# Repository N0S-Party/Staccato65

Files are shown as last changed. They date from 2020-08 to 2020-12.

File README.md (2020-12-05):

# Staccato65

[][cc-by-nc-sa]

A 65% board with OLED, rotary encoder support, and a 3D printed case.

Keyboard_black

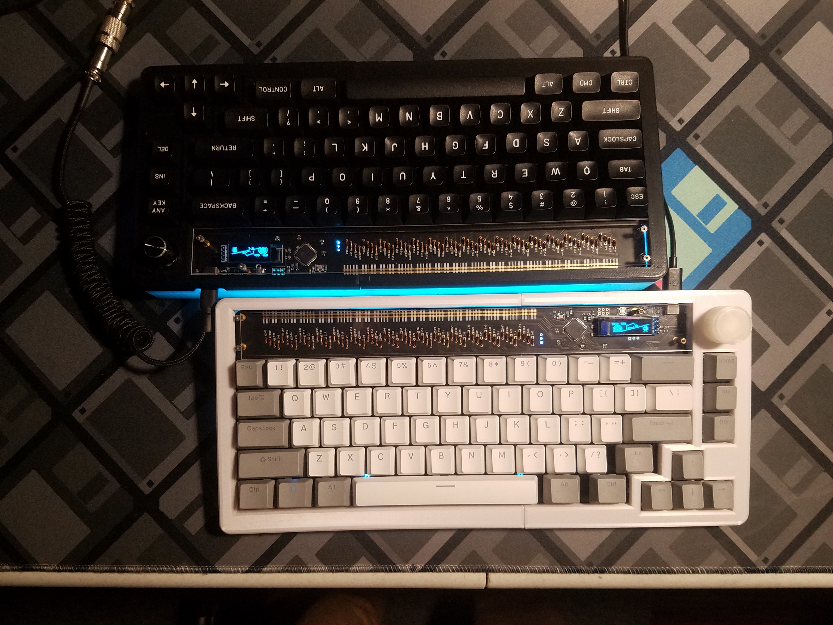
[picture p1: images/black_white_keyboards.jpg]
Keyboard_black_white


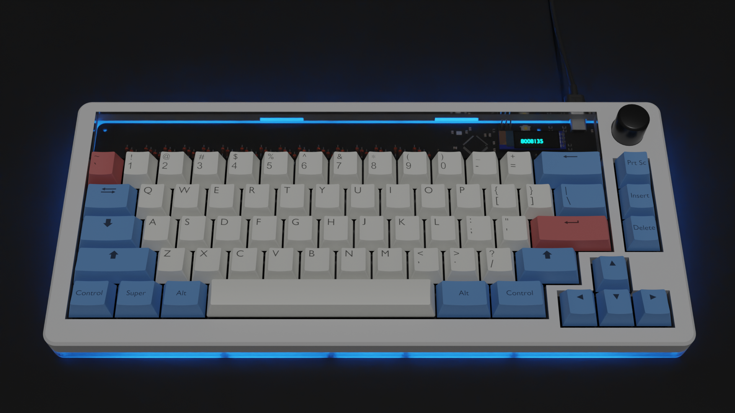
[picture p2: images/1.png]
Keyboard


**Specs:** 
* 3D printed case (top mounted)
* rotary encoder support
* OLED screen
* ATMega32u4 as microcontroller
* USB C connector (with USB 2.0)
* choice of a stepped caps lock
* hot-swappable (if I don't end up cutting costs!)

**Design goals:**
* separated arrow keys
* 1.5u alt & ctrl keys with 1.75u shift
* aesthetically pleasing through-hole diode layout on the front layer

Basically the layout will be similar to the Satisfaction75 and ID80, but without the function row. 
I also really like the look of the Discipline keyboards, so the layout of the diodes will somewhat try to reflect that. 

One of my current concerns is that the firmware size might end up too big, since I'll have to use QMK's I2C and roatry encoder libraries in addition to multiple keyboard layouts -- 
but I guess we'll see once we get there.

## Update 8/1
I started building the key matrix in the schematic. I originally wanted the schematic matrix to have a 1-to-1 mapping to the keyboard layout. 
It's actually done that way for the schematic of the Discipline, making it easy to route the traces for the PCB, and organize the layout even pre-PCB design.
Unfortunately, it ended up being 15 columns by 6 rows for me. 
This was far too many pins to support for the ATmega32u4 since I need to save some pins to support the rotary encoder and OLED. 
I'm also planning to save the SCK, MOSI and MISO pins for ISP usage, in case I ever want to set fuse bits 
(though I'm willing to give these pins up if desperate measures need to be in play).

## Update 8/4
Modified the matrix to now use 10 columns and 7 rows. This allows for a maximum of 69 switches and 1 rotary encoder switch. With the rotary encoder and OLED screen added, this oleaves the microcontroller with only one GPIO pin available (which means I *could* turn this into a 75% keyboard). I did come across [mr.keeb's PCB generator](https://builder.mrkeebs.com), but for some reason there is a bug that messes up the layout if you use a non-standard matrix; Can't say I'm not happy, since this means that my previous work wasn't all for nothing. I'm planning on using Kailh hot-swap sockets, but I might undo this if I find that it's too costly. 

## Update 8/6
Got to making the key layout on the PCB. I'm thankful I have a spare top plate and a caliper to help me confirm my switch placement. A modification I made from my initial plan is that I'm now using the "columns" in the schematics as rows. I need about 14 keys per row, and have 7 keys per column in the schematic makes that transform easy. I'll now have two disjoint traces per row on the PCB. Also, I can't get that damn encoder footprint to be centered... I'll leave that for next time.

## Update 8/12
I haven't updated here in a while, but that doesn't mean I haven't been working hard! I've finally managed to finish routing the PCB to a degree that I'm satisfied with. I might have to work a bit more on making the top right routing better, but I'd say the key routing was not too shabby. Fun fact, using Kicad 5.0.2 makes routing a pain. Traces never consistently "stuck" to each other the way I wanted it to. Thankfully, Kicad 5.1.6 was way more route-friendly. Unfortunately I couldn't really group the traces into fours that were aligned with the diode groups since some of the rows contained five switches instead of four. Nevertheless, clean routing was still possible and it still looks good as long as you don't look at it too hard. See below for pictures (you can see what I was talking about with the schematic matrix not being entirely 1-to-1 in dimension to the keyboard).

PCB and Schematics pictured are outdated. Please see the repo files for the updated versions
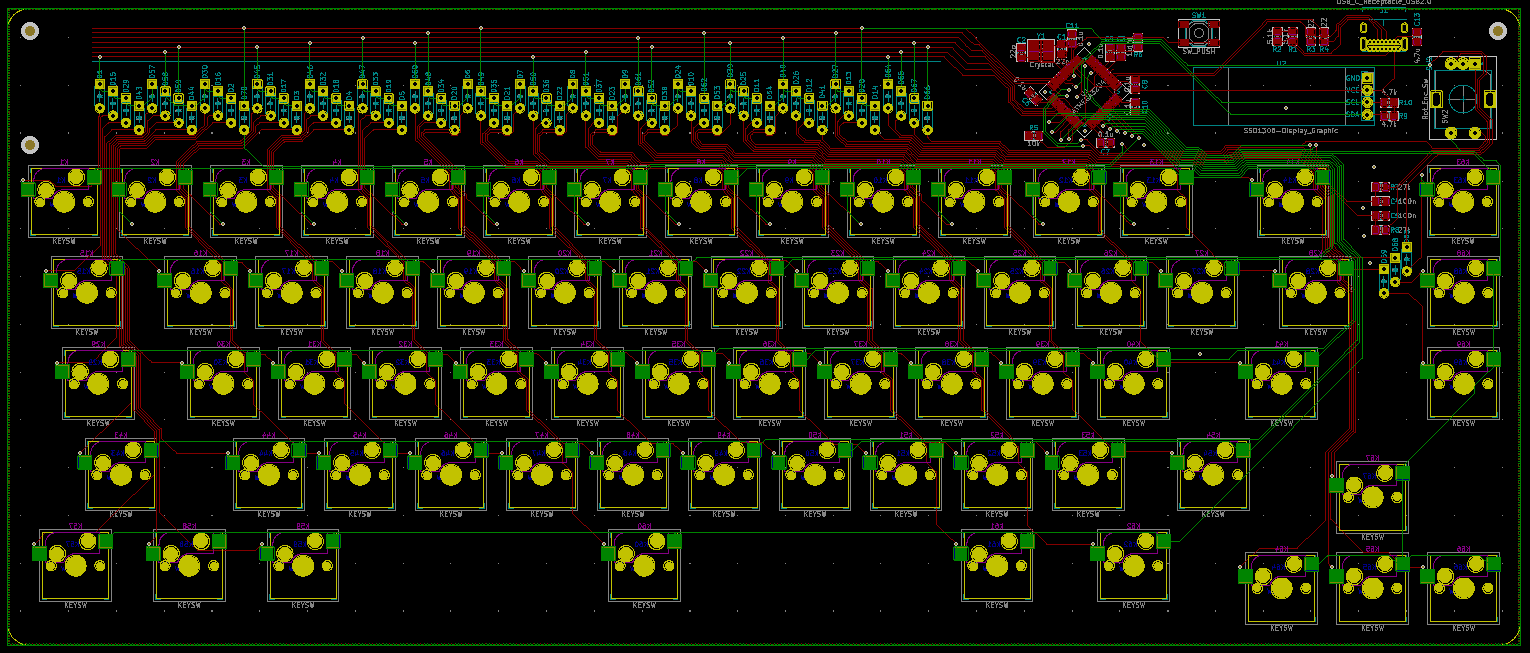
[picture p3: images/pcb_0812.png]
PCB


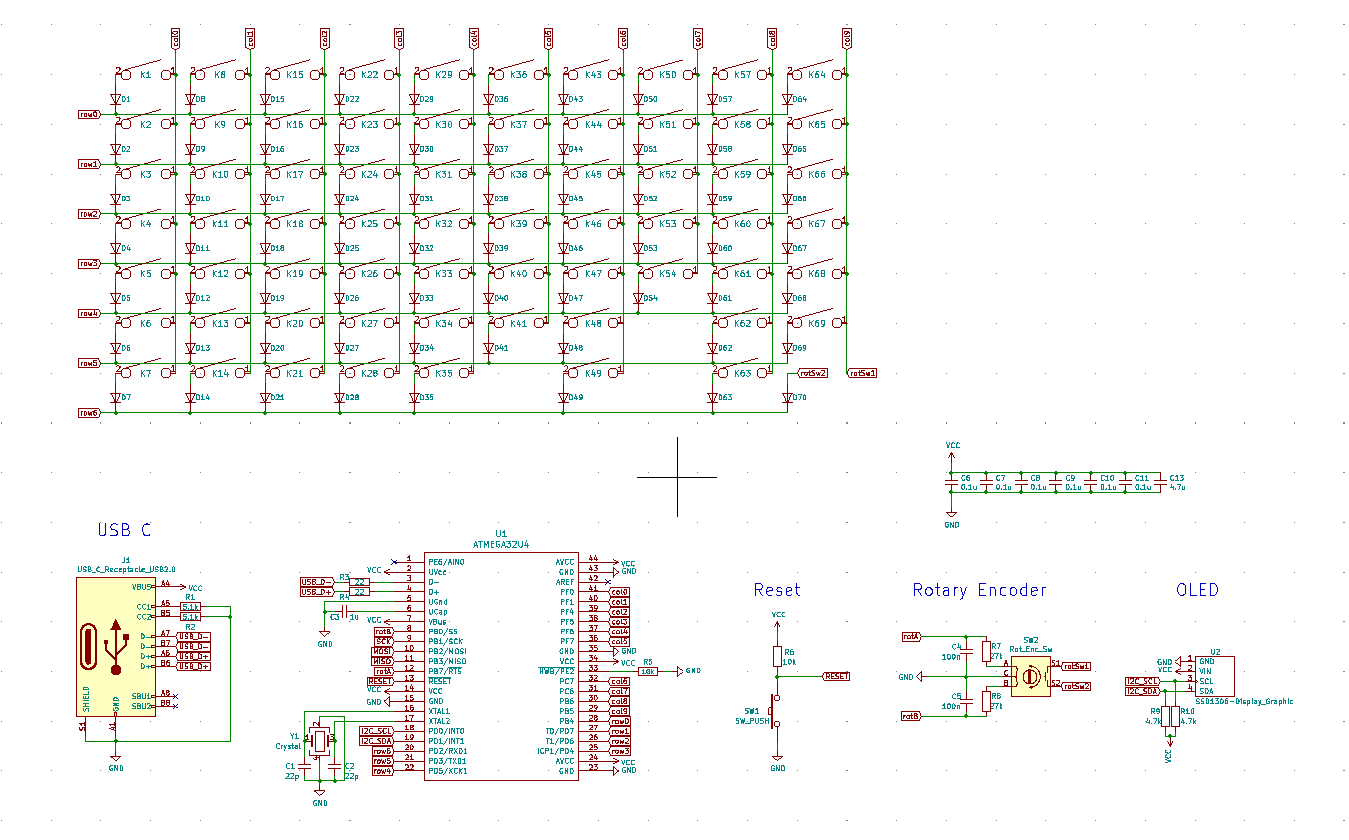
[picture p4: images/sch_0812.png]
Schematic


## Update 12/5
Okay, I don't know if anyone was following this project, but while it did seem like I had a long hiatus, I was actually working quite a bit behind the scenes. 
With the help of Sagar, and another friend of ours, we managed to get the first few prototypes out. Many revisions had to be done with the case due to 3D printing tolerances and the limitations of a 3D printer. Another issue that was caught was that the PCB plate cutout for the spacebar stabilizer was actually facing the wrong way. Unfortunately I only found this out after I got the first batch delivered, so I just had to file down the troublesome cutout by a few milimeters. Ordering from JLC PCB, the cumulative costs of PCB + plate + parts is about 70 dollars, assuming you order a batch of 10. Surprisingly, we managed to get a small groupbuy going and will be making 10 keyboards for us and a few other friends. In terms of regrets, I maybe should have opted to pay for assembly costs from the fab as well, since soldering a keyboard takes about 4 hours total. But hey, I'm really good at drag soldering now at least. As for actual release, I'm not too confident in my PCB design skills yet to release a product to members of the community. If I ever had to refine this design for a round 2, I'd probably add ESD protection, fix the plate and also make some of the footprint placements nicer. Overall, I plan to make a macropad as my next project. The reasoning is so I could try out more experimental features that I've had in mind while keeping the risk low. We also hope to make a case out of metal, which may be a challenge in itself. 

This work is licensed under a
[Creative Commons Attribution-NonCommercial-ShareAlike 4.0 International License][cc-by-nc-sa].

[][cc-by-nc-sa]

[cc-by-nc-sa]: http://creativecommons.org/licenses/by-nc-sa/4.0/
[cc-by-nc-sa-image]: https://licensebuttons.net/l/by-nc-sa/4.0/88x31.png
[cc-by-nc-sa-shield]: https://img.shields.io/badge/License-CC%20BY--NC--SA%204.0-lightgrey.svg

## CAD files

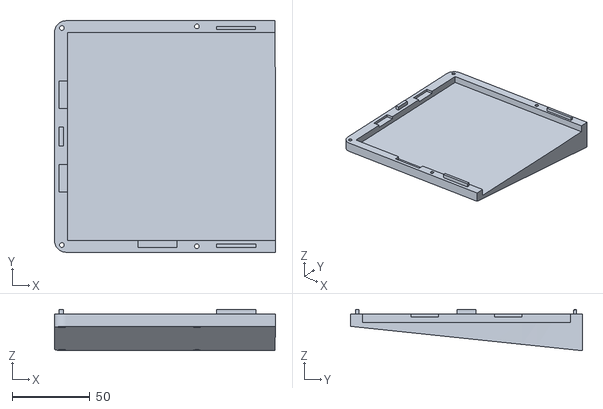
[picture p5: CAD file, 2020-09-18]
3d/case_bottom_left.stl
142.2 x 149.0 x 26.7

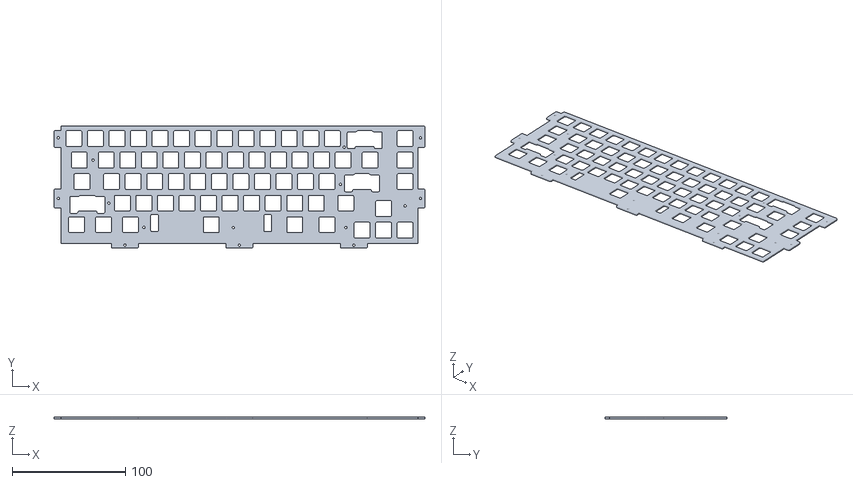
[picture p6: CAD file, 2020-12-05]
keybored_plate/staccato65_plate.obj
328.1 x 108.0 x 1.60

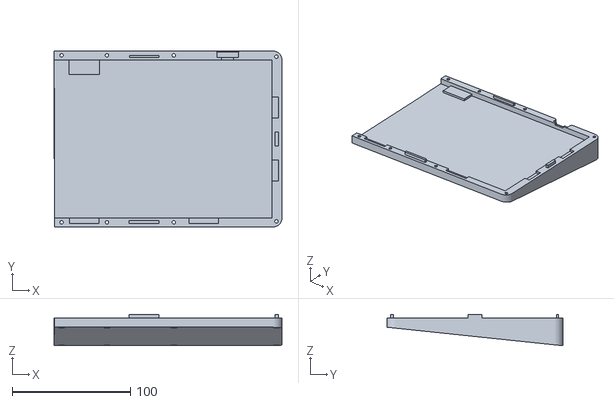
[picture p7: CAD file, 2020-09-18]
3d/case_bottom_right.stl
193.2 x 149.0 x 26.7

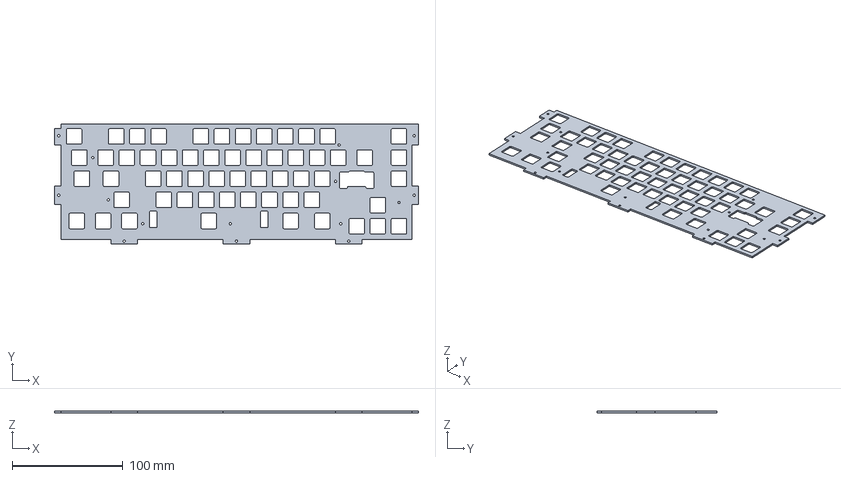
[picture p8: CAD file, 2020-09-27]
keybored_plate/keybored_plate.step
328.1 x 108.0 x 1.60 mm

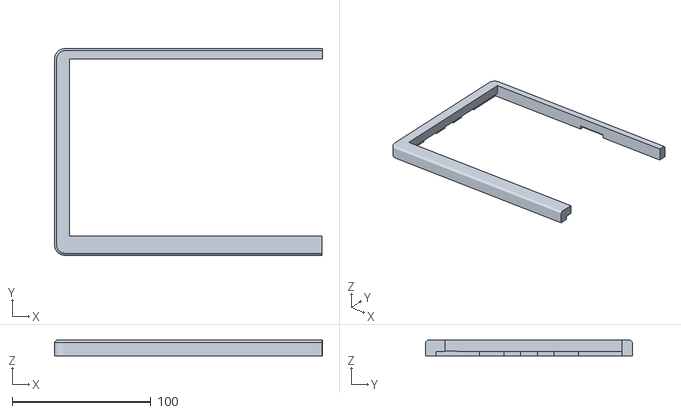
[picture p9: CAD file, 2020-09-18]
3d/case_top_left.stl
193.2 x 149.0 x 11.3

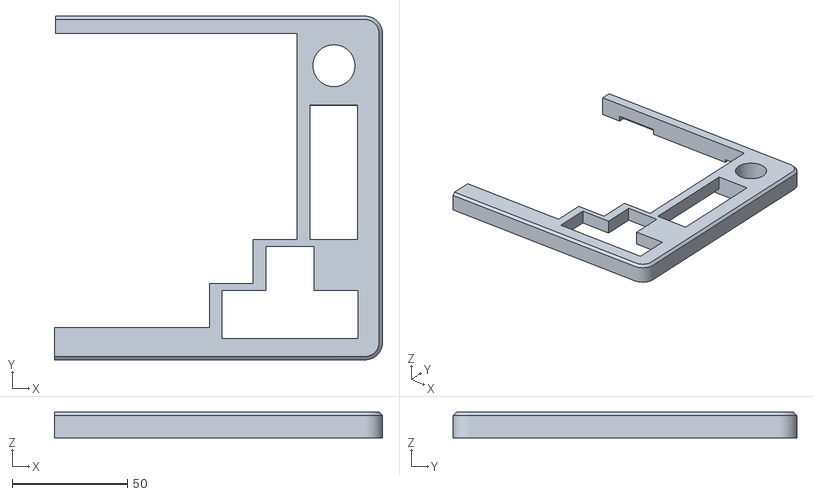
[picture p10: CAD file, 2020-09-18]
3d/case_top_right.stl
142.2 x 149.0 x 11.3

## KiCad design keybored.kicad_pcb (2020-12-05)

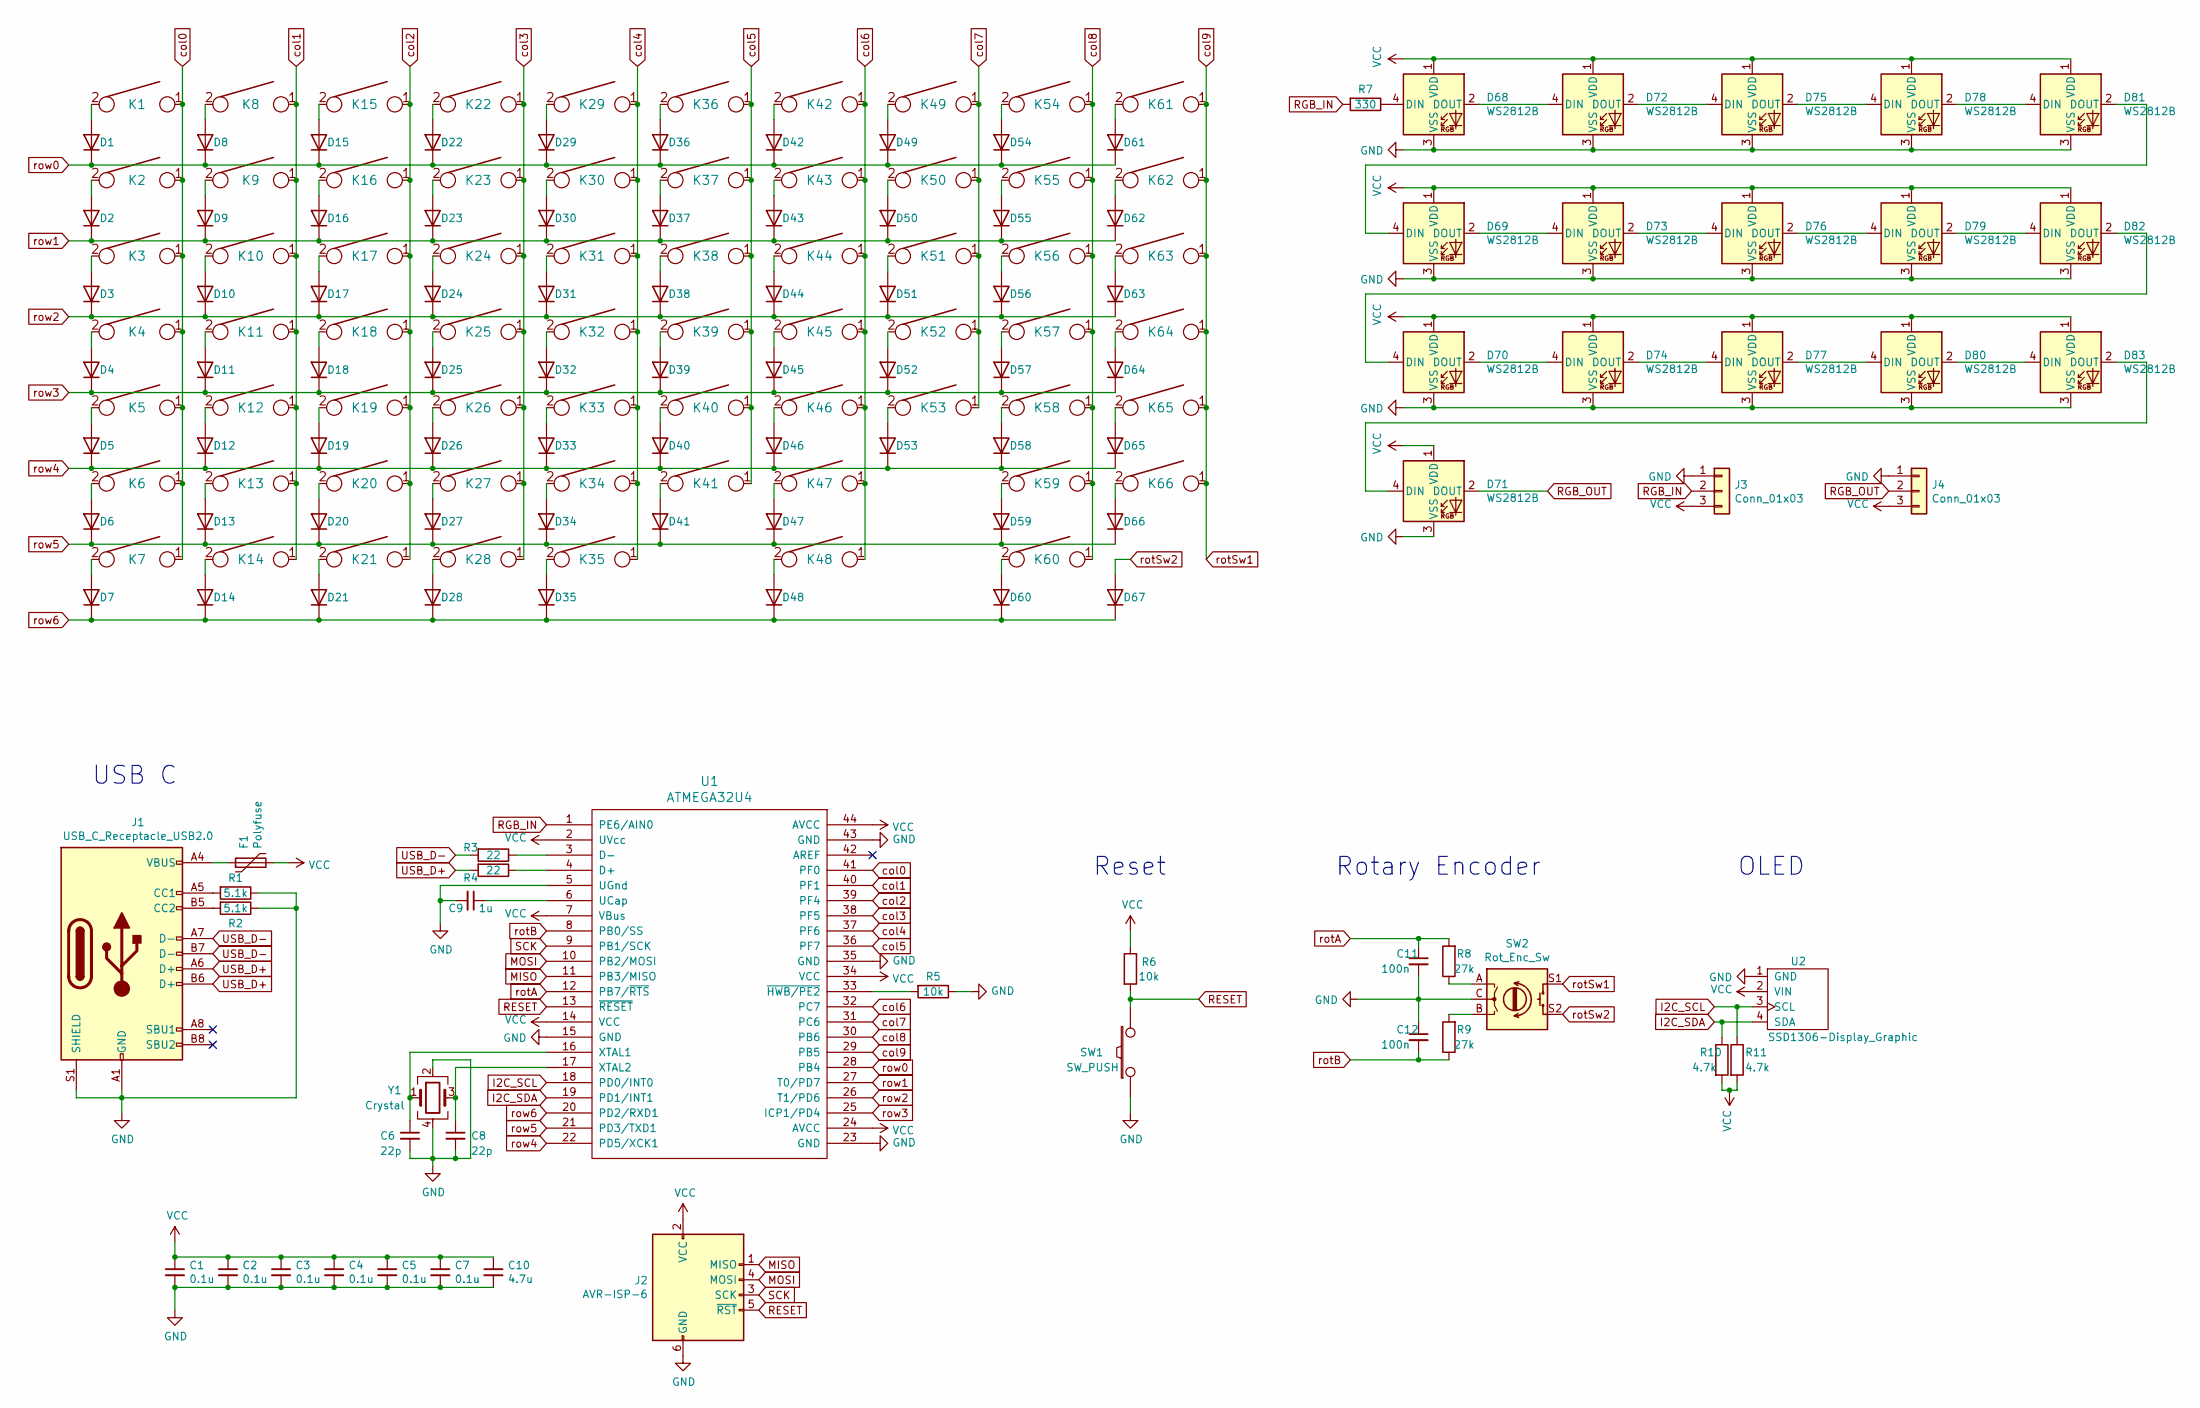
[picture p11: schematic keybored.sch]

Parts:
C1, C2, C3, C4, C5, C7: 0.1u; C_0805_2012Metric_Pad1.15x1.40mm_HandSolder
C6, C8: 22p; C_0805_2012Metric_Pad1.15x1.40mm_HandSolder
C9: 1u; C_0805_2012Metric_Pad1.15x1.40mm_HandSolder
C10: 4.7u; C_0805_2012Metric_Pad1.15x1.40mm_HandSolder
C11, C12: 100n; C_0805_2012Metric_Pad1.15x1.40mm_HandSolder
D1, D2, D3, D4, D5, D6, D7, D8, D9, D10, D11, D12, D13, D14, D15, D16, D17, D18, D19, D20, D21, D22, D23, D24, D25, D26, D27, D28, D29, D30, D31, D32, D33, D34, D35, D36, D37, D38, D39, D40, D41, D42, D43, D44, D45, D46, D47, D48, D49, D50, D51, D52, D53, D54, D55, D56, D57, D58, D59, D60, D61, D62, D63, D64, D65, D66, D67: D; DO-35_SOD27_5.08mm
D68, D69, D70, D71, D72, D73, D74, D75, D76, D77, D78, D79, D80, D81, D82, D83: WS2812B; LED_WS2812B_PLCC4_5.0x5.0mm_P3.2mm
F1: Polyfuse
J1: USB_C_Receptacle_USB2.0; USB_C_GCT_USB4085
J2: AVR-ISP-6; PinHeader_2x03_P2.54mm_Vertical
J3, J4: Conn_01x03; PinHeader_1x03_P2.54mm_Vertical
K1, K2, K3, K4, K5, K6, K7, K8, K9, K10, K11, K12, K13, K14, K15, K16, K17, K18, K19, K20, K21, K22, K23, K24, K25, K26, K27, K28, K29, K30, K31, K32, K33, K34, K35, K36, K37, K38, K39, K40, K41, K42, K43, K44, K45, K46, K47, K48, K49, K50, K51, K52, K53, K54, K55, K56, K57, K58, K59, K60, K61, K62, K63, K64, K65, K66: KEYSW; Kailh_socket_MX_optional
R1, R2: 5.1k; R_0805_2012Metric_Pad1.15x1.40mm_HandSolder
R3, R4: 22; R_0805_2012Metric_Pad1.15x1.40mm_HandSolder
R5, R6: 10k; R_0805_2012Metric_Pad1.15x1.40mm_HandSolder
R7: 330; R_0805_2012Metric_Pad1.15x1.40mm_HandSolder
R8, R9: 27k; R_0805_2012Metric_Pad1.15x1.40mm_HandSolder
R10, R11: 4.7k; R_0805_2012Metric_Pad1.15x1.40mm_HandSolder
SW1: SW_PUSH; SW_SPST_TL3342
SW2: Rot_Enc_Sw; RotaryEncoder_Alps_EC11E-Switch_Vertical_H20mm
U1: ATMEGA32U4; TQFP-44_10x10mm_P0.8mm
U2: SSD1306-Display_Graphic; SSD1306_OLED_128x32_0.91_inch
Y1: Crystal; Crystal_SMD_SeikoEpson_FA238-4Pin_3.2x2.5mm_HandSoldering

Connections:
GND: C1.2, C2.2, C3.2, C4.2, C5.2, C6.2, C7.2, C8.2, C9.2, C10.2, C11.2, C12.1, D68.3 (VSS), D69.3 (VSS), D70.3 (VSS), D71.3 (VSS), D72.3 (VSS), D73.3 (VSS), D74.3 (VSS), D75.3 (VSS), D76.3 (VSS), D77.3 (VSS), D78.3 (VSS), D79.3 (VSS), D80.3 (VSS), D81.3 (VSS), D82.3 (VSS), D83.3 (VSS), J1.A1 (GND), J1.A12 (GND), J1.B1 (GND), J1.B12 (GND), J1.S1 (SHIELD), J2.6 (GND), J3.1, J4.1, R1.1, R2.1, R5.1, SW1.1, SW2.C, U1.5 (UGnd), U1.15 (GND), U1.23 (GND), U1.35 (GND), U1.43 (GND), U2.1 (GND), Y1.2, Y1.4
I2C_SCL: R11.1, U1.18 (PD0/INT0), U2.3 (SCL)
I2C_SDA: R10.1, U1.19 (PD1/INT1), U2.4 (SDA)
MISO: J2.1 (MISO), U1.11 (PB3/MISO)
MOSI: J2.4 (MOSI), U1.10 (PB2/MOSI)
unnamed: C6.1, U1.16 (XTAL1), Y1.1
unnamed: C8.1, U1.17 (XTAL2), Y1.3
unnamed: C9.1, U1.6 (UCap)
unnamed: D1.2 (A), K1.2
unnamed: D2.2 (A), K2.2
unnamed: D3.2 (A), K3.2
unnamed: D4.2 (A), K4.2
unnamed: D5.2 (A), K5.2
unnamed: D6.2 (A), K6.2
unnamed: D7.2 (A), K7.2
unnamed: D8.2 (A), K8.2
unnamed: D9.2 (A), K9.2
unnamed: D10.2 (A), K10.2
unnamed: D11.2 (A), K11.2
unnamed: D12.2 (A), K12.2
unnamed: D13.2 (A), K13.2
unnamed: D14.2 (A), K14.2
unnamed: D15.2 (A), K15.2
unnamed: D16.2 (A), K16.2
unnamed: D17.2 (A), K17.2
unnamed: D18.2 (A), K18.2
unnamed: D19.2 (A), K19.2
unnamed: D20.2 (A), K20.2
unnamed: D21.2 (A), K21.2
unnamed: D22.2 (A), K22.2
unnamed: D23.2 (A), K23.2
unnamed: D24.2 (A), K24.2
unnamed: D25.2 (A), K25.2
unnamed: D26.2 (A), K26.2
unnamed: D27.2 (A), K27.2
unnamed: D28.2 (A), K28.2
unnamed: D29.2 (A), K29.2
unnamed: D30.2 (A), K30.2
unnamed: D31.2 (A), K31.2
unnamed: D32.2 (A), K32.2
unnamed: D33.2 (A), K33.2
unnamed: D34.2 (A), K34.2
unnamed: D35.2 (A), K35.2
unnamed: D36.2 (A), K36.2
unnamed: D37.2 (A), K37.2
unnamed: D38.2 (A), K38.2
unnamed: D39.2 (A), K39.2
unnamed: D40.2 (A), K40.2
unnamed: D41.2 (A), K41.2
unnamed: D42.2 (A), K42.2
unnamed: D43.2 (A), K43.2
unnamed: D44.2 (A), K44.2
unnamed: D45.2 (A), K45.2
unnamed: D46.2 (A), K46.2
unnamed: D47.2 (A), K47.2
unnamed: D48.2 (A), K48.2
unnamed: D49.2 (A), K49.2
unnamed: D50.2 (A), K50.2
unnamed: D51.2 (A), K51.2
unnamed: D52.2 (A), K52.2
unnamed: D53.2 (A), K53.2
unnamed: D54.2 (A), K54.2
unnamed: D55.2 (A), K55.2
unnamed: D56.2 (A), K56.2
unnamed: D57.2 (A), K57.2
unnamed: D58.2 (A), K58.2
unnamed: D59.2 (A), K59.2
unnamed: D60.2 (A), K60.2
unnamed: D61.2 (A), K61.2
unnamed: D62.2 (A), K62.2
unnamed: D63.2 (A), K63.2
unnamed: D64.2 (A), K64.2
unnamed: D65.2 (A), K65.2
unnamed: D66.2 (A), K66.2
unnamed: D68.2 (DOUT), D72.4 (DIN)
unnamed: D68.4 (DIN), R7.1
unnamed: D69.2 (DOUT), D73.4 (DIN)
unnamed: D69.4 (DIN), D81.2 (DOUT)
unnamed: D70.2 (DOUT), D74.4 (DIN)
unnamed: D70.4 (DIN), D82.2 (DOUT)
unnamed: D71.4 (DIN), D83.2 (DOUT)
unnamed: D72.2 (DOUT), D75.4 (DIN)
unnamed: D73.2 (DOUT), D76.4 (DIN)
unnamed: D74.2 (DOUT), D77.4 (DIN)
unnamed: D75.2 (DOUT), D78.4 (DIN)
unnamed: D76.2 (DOUT), D79.4 (DIN)
unnamed: D77.2 (DOUT), D80.4 (DIN)
unnamed: D78.2 (DOUT), D81.4 (DIN)
unnamed: D79.2 (DOUT), D82.4 (DIN)
unnamed: D80.2 (DOUT), D83.4 (DIN)
unnamed: J1.A5 (CC1), R1.2
unnamed: J1.B5 (CC2), R2.2
unnamed: R3.1, U1.3 (D-)
unnamed: R4.1, U1.4 (D+)
unnamed: R5.2, U1.33 (~HWB/PE2)
unnamed: R8.1, SW2.A
unnamed: R9.2, SW2.B
RESET: J2.5 (~RST), R6.2, SW1.2, U1.13 (~RESET)
RGB_IN: J3.2, R7.2, U1.1 (PE6/AIN0)
RGB_OUT: D71.2 (DOUT), J4.2
SCK: J2.3 (SCK), U1.9 (PB1/SCK)
USB_D+: J1.A6 (D+), J1.B6 (D+), R4.2
USB_D-: J1.A7 (D-), J1.B7 (D-), R3.2
col0: K1.1, K2.1, K3.1, K4.1, K5.1, K6.1, K7.1, U1.41 (PF0)
col1: K8.1, K9.1, K10.1, K11.1, K12.1, K13.1, K14.1, U1.40 (PF1)
col2: K15.1, K16.1, K17.1, K18.1, K19.1, K20.1, K21.1, U1.39 (PF4)
col3: K22.1, K23.1, K24.1, K25.1, K26.1, K27.1, K28.1, U1.38 (PF5)
col4: K29.1, K30.1, K31.1, K32.1, K33.1, K34.1, K35.1, U1.37 (PF6)
col5: K36.1, K37.1, K38.1, K39.1, K40.1, K41.1, U1.36 (PF7)
col6: K42.1, K43.1, K44.1, K45.1, K46.1, K47.1, K48.1, U1.32 (PC7)
col7: K49.1, K50.1, K51.1, K52.1, K53.1, U1.31 (PC6)
col8: K54.1, K55.1, K56.1, K57.1, K58.1, K59.1, K60.1, U1.30 (PB6)
col9: K61.1, K62.1, K63.1, K64.1, K65.1, K66.1, SW2.S1, U1.29 (PB5)
rotA: C11.1, R8.2, U1.12 (PB7/~RTS)
rotB: C12.2, R9.1, U1.8 (PB0/SS)
rotSw2: D67.2 (A), SW2.S2
row0: D1.1 (K), D8.1 (K), D15.1 (K), D22.1 (K), D29.1 (K), D36.1 (K), D42.1 (K), D49.1 (K), D54.1 (K), D61.1 (K), U1.28 (PB4)
row1: D2.1 (K), D9.1 (K), D16.1 (K), D23.1 (K), D30.1 (K), D37.1 (K), D43.1 (K), D50.1 (K), D55.1 (K), D62.1 (K), U1.27 (T0/PD7)
row2: D3.1 (K), D10.1 (K), D17.1 (K), D24.1 (K), D31.1 (K), D38.1 (K), D44.1 (K), D51.1 (K), D56.1 (K), D63.1 (K), U1.26 (T1/PD6)
row3: D4.1 (K), D11.1 (K), D18.1 (K), D25.1 (K), D32.1 (K), D39.1 (K), D45.1 (K), D52.1 (K), D57.1 (K), D64.1 (K), U1.25 (ICP1/PD4)
row4: D5.1 (K), D12.1 (K), D19.1 (K), D26.1 (K), D33.1 (K), D40.1 (K), D46.1 (K), D53.1 (K), D58.1 (K), D65.1 (K), U1.22 (PD5/XCK1)
row5: D6.1 (K), D13.1 (K), D20.1 (K), D27.1 (K), D34.1 (K), D41.1 (K), D47.1 (K), D59.1 (K), D66.1 (K), U1.21 (PD3/TXD1)
row6: D7.1 (K), D14.1 (K), D21.1 (K), D28.1 (K), D35.1 (K), D48.1 (K), D60.1 (K), D67.1 (K), U1.20 (PD2/RXD1)

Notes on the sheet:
Reset
Rotary Encoder
OLED
USB C

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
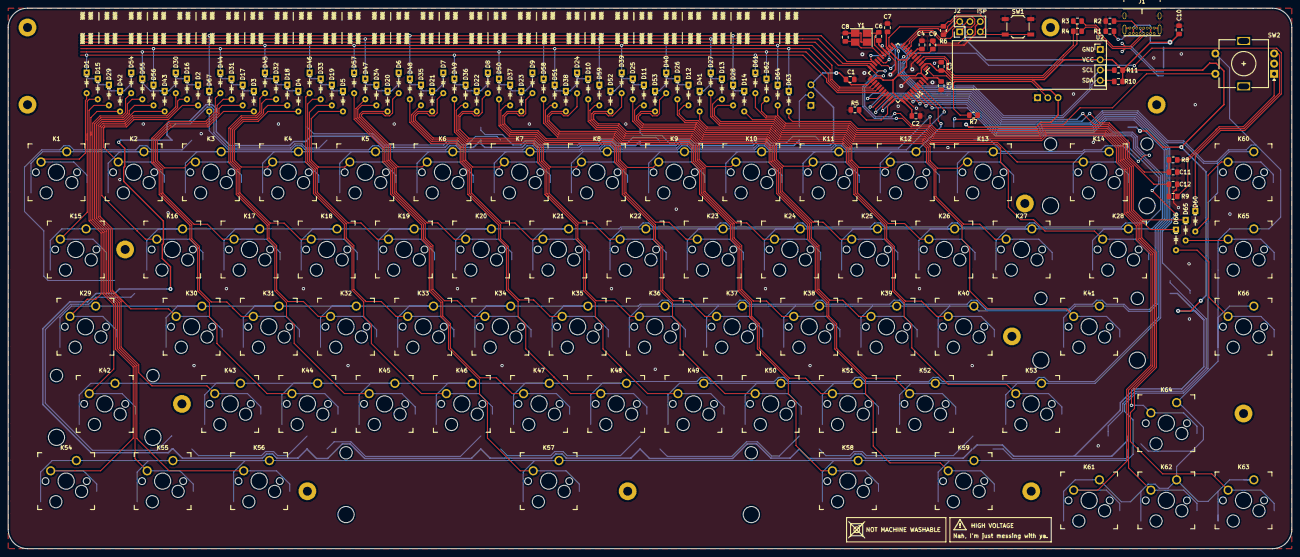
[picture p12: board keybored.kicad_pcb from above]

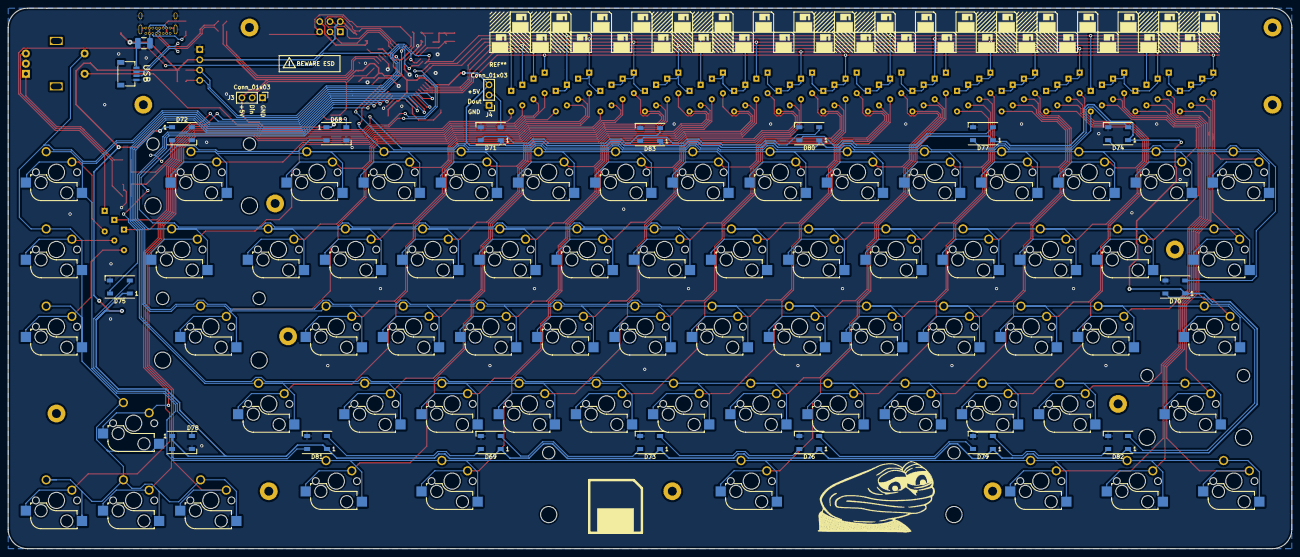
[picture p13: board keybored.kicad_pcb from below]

Board: 2 copper layers, 316.7 x 133.3 mm, 181 parts (18 on the bottom side), 124 nets.

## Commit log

2020-08-01 Added Schematic
    - USB, reset implemented
    - matrix pinouts still WIP
    [keybored.sch]
2020-08-04 Designations and footprints assigned
    - added component references + footprints
    - started PCB design
    - added rotary encoder and OLED
    [keybored.kicad_pcb, keybored.sch]
2020-08-06 Key layout done
    [keybored.kicad_pcb]
2020-08-10 Diode layout and row routing
    [keybored.kicad_pcb, keybored.sch]
2020-08-13 Finished PCB routing rev 1
    [keybored-B_Cu.gbr, keybored-B_Mask.gbr, keybored-B_Paste.gbr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]
2020-08-13 Added images of PCB and schematic
2020-08-13 Updated PCB image
    [keybored.kicad_pcb]
2020-08-19 Fix typo in README
    [keybored.sch]
2020-08-19 Major pcb changes
    - now uses a dual footprint for switches
    - added ARGB support
    - added stabilizer holes
    - added header pin support for ISP
    [keybored.kicad_pcb, keybored.sch]
2020-09-15 Add plate, updates to PCB
    [keybored.kicad_pcb, keybored.sch]
2020-09-15 Actually add the plate files this time
    [keybored_plate-B_Cu.gbr, keybored_plate-B_Mask.gbr, keybored_plate-B_Paste.gbr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]
2020-09-16 add led underglow
2020-09-18 split case into 3d printable stls, add a gitignore
    [case_bottom_left.stl, case_bottom_right.stl, case_top_left.stl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]
2020-09-27 Updates to PCB + Plate
    - plate dimensions fixed
    - cutouts for stabilizers added
    - spacebar stabilizer holes added to PCB
    - moved RGB LEDs on PCB
    [keybored.kicad_pcb, keybored_plate.kicad_pcb, keybored_plate.step]
2020-09-27 Final touches on PCB and Plate
    - added decals and memes on PCB + plate
    - copper fill added for plate
    - final commit before prototype order
    [keybored-B_Cu.gbr, keybored-B_Mask.gbr, keybored-B_Paste.gbr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]
2020-12-05 Updates to keyboard PCB and Plate
    [keybored-B_Cu.gbr, keybored-B_Mask.gbr, keybored-B_Paste.gbr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]
2020-12-05 Update README.md
    - added update and real prototype images

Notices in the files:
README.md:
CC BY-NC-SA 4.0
